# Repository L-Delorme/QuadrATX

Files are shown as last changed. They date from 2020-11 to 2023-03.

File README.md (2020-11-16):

# QuadrATX
ATX mod for the Macintosh Quadra 900/950

This is a work in progress mod. The AC Board has not been fully tested. Use at your own risk.
The BOM has not been finalized. 
Instructions on how to build a QuadrATX kit will follow. 

Hardware protected by CC-BY-NC-SA-4.0 (Attribution-NonCommercial-ShareAlike)
https://creativecommons.org/licenses/by-nc-sa/4.0/

If you wish to sell this product, please contact me beforehand. 
theapplechronicles AT gmail DOT com

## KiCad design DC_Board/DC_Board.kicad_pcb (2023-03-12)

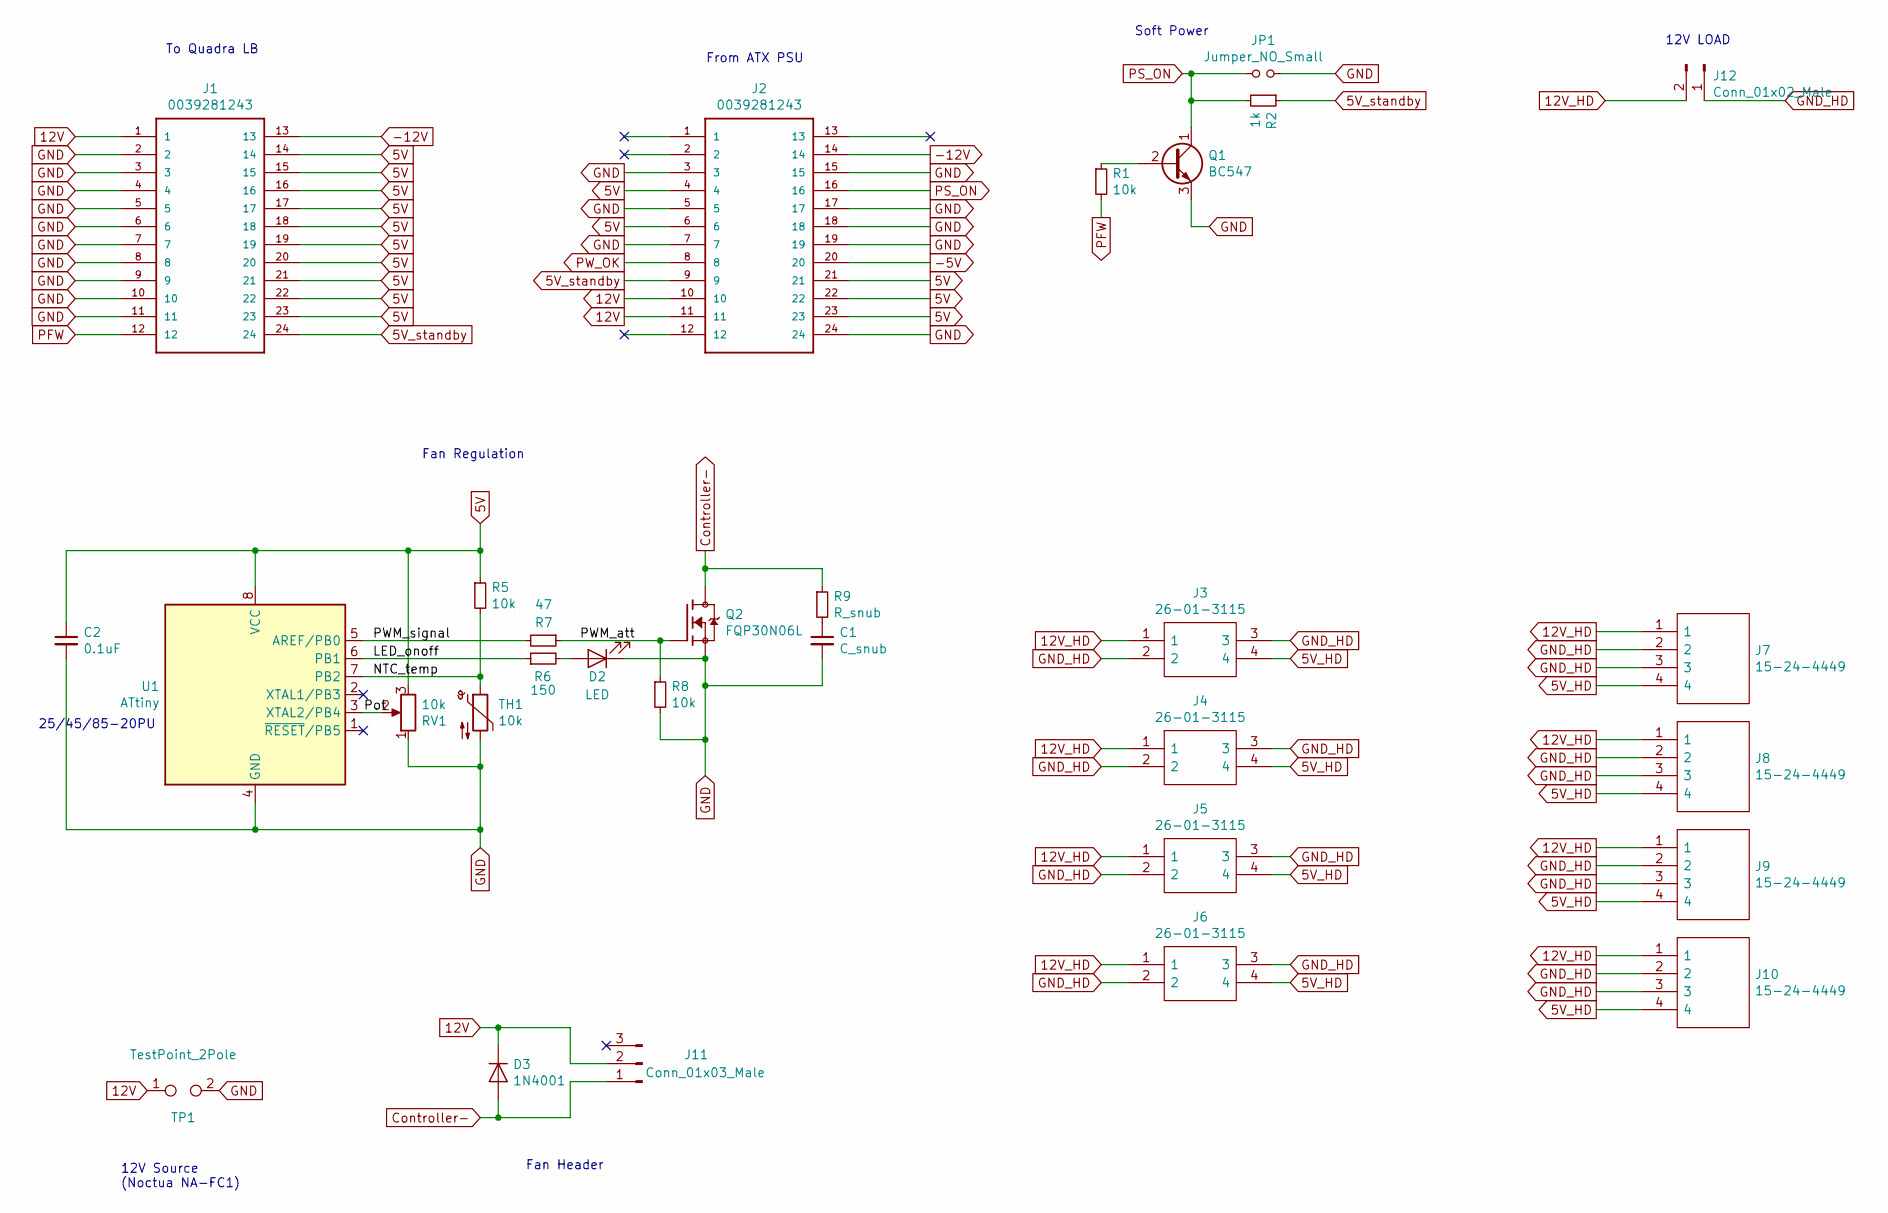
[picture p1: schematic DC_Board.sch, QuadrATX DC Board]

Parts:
C1: C_snub; C_Rect_L9.0mm_W2.5mm_P7.50mm_MKT
C2: 0.1uF; C_Disc_D4.7mm_W2.5mm_P5.00mm
D2: LED; LED_D5.0mm
D3: 1N4001; D_DO-41_SOD81_P10.16mm_Horizontal
J1: 0039281243; Molex_Mini-Fit_Jr_5566-24A2_2x12_P4.20mm_Vertical
J2: 0039281243; Molex_Mini-Fit_Jr_5566-24A_2x12_P4.20mm_Vertical
J3, J4, J5, J6: 26-01-3115; 39-30-1040; Manufacturer_Part_Number 26-01-3115; Mouser Part Number 538-26-01-3115
J7, J8, J9, J10: 15-24-4449; 641737-1; Manufacturer_Part_Number 15-24-4449; Mouser Part Number 538-15-24-4449
J11: Conn_01x03_Male; Molex_KK-254_AE-6410-03A_1x03_P2.54mm_Vertical
J12: Conn_01x02_Male; Molex_KK-396_A-41791-0002_1x02_P3.96mm_Vertical
JP1: Jumper_NO_Small; PinSocket_1x02_P2.54mm_Vertical
Q1: BC547; TO-92L_Wide
Q2: FQP30N06L; TO-220F-3_Horizontal_TabDown
R1, R5, R8: 10k; R_Axial_DIN0309_L9.0mm_D3.2mm_P15.24mm_Horizontal
R2: 1k; R_Axial_DIN0309_L9.0mm_D3.2mm_P15.24mm_Horizontal
R6: 150; R_Axial_DIN0309_L9.0mm_D3.2mm_P15.24mm_Horizontal
R7: 47; R_Axial_DIN0309_L9.0mm_D3.2mm_P15.24mm_Horizontal
R9: R_snub; R_Axial_DIN0309_L9.0mm_D3.2mm_P15.24mm_Horizontal
RV1: 10k; 3386P-1-103LF
TH1: 10k; R_Axial_DIN0309_L9.0mm_D3.2mm_P15.24mm_Horizontal
TP1: TestPoint_2Pole; PinHeader_2x01_P2.54mm_Vertical
U1: ATtiny; DIP-8_W7.62mm

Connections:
5V: C2.1, J1.14, J1.15, J1.16, J1.17, J1.18, J1.19, J1.20, J1.21, J1.22, J1.23, J2.4, J2.6, J2.21, J2.22, J2.23, R5.1, RV1.3, U1.8 (VCC)
5V_HD: J3.4, J4.4, J5.4, J6.4, J7.4, J8.4, J9.4, J10.4
5V_standby: J1.24, J2.9, R2.1
12V: D3.1 (K), J1.1, J2.10, J2.11, J11.2, TP1.1
12V_HD: J3.1, J4.1, J5.1, J6.1, J7.1, J8.1, J9.1, J10.1, J12.2
-5V: J2.20
-12V: J1.13, J2.14
/LED_onoff: R6.1, U1.6 (PB1)
/NTC_temp: R5.2, TH1.1, U1.7 (PB2)
/PWM_att: Q2.1, R7.1, R8.1
/PWM_signal: R7.2, U1.5 (AREF/PB0)
/Pot: RV1.2, U1.3 (XTAL2/PB4)
Controller-: D3.2 (A), J11.1, Q2.2, R9.1
GND: C1.2, C2.2, D2.1 (K), J1.2, J1.3, J1.4, J1.5, J1.6, J1.7, J1.8, J1.9, J1.10, J1.11, J2.3, J2.5, J2.7, J2.15, J2.17, J2.18, J2.19, J2.24, JP1.2, Q1.3 (E), Q2.3, R8.2, RV1.1, TH1.2, TP1.2, U1.4 (GND)
GND_HD: J3.2, J3.3, J4.2, J4.3, J5.2, J5.3, J6.2, J6.3, J7.2, J7.3, J8.2, J8.3, J9.2, J9.3, J10.2, J10.3, J12.1
unnamed: C1.1, R9.2
unnamed: D2.2 (A), R6.2
unnamed: Q1.2 (B), R1.1
PFW: J1.12, R1.2
PS_ON: J2.16, JP1.1, Q1.1 (C), R2.2
PW_OK: J2.8

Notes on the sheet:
From ATX PSU
Soft Power
12V LOAD
To Quadra LB
Fan Regulation
25/45/85-20PU
12V Source (Noctua NA-FC1)
Fan Header

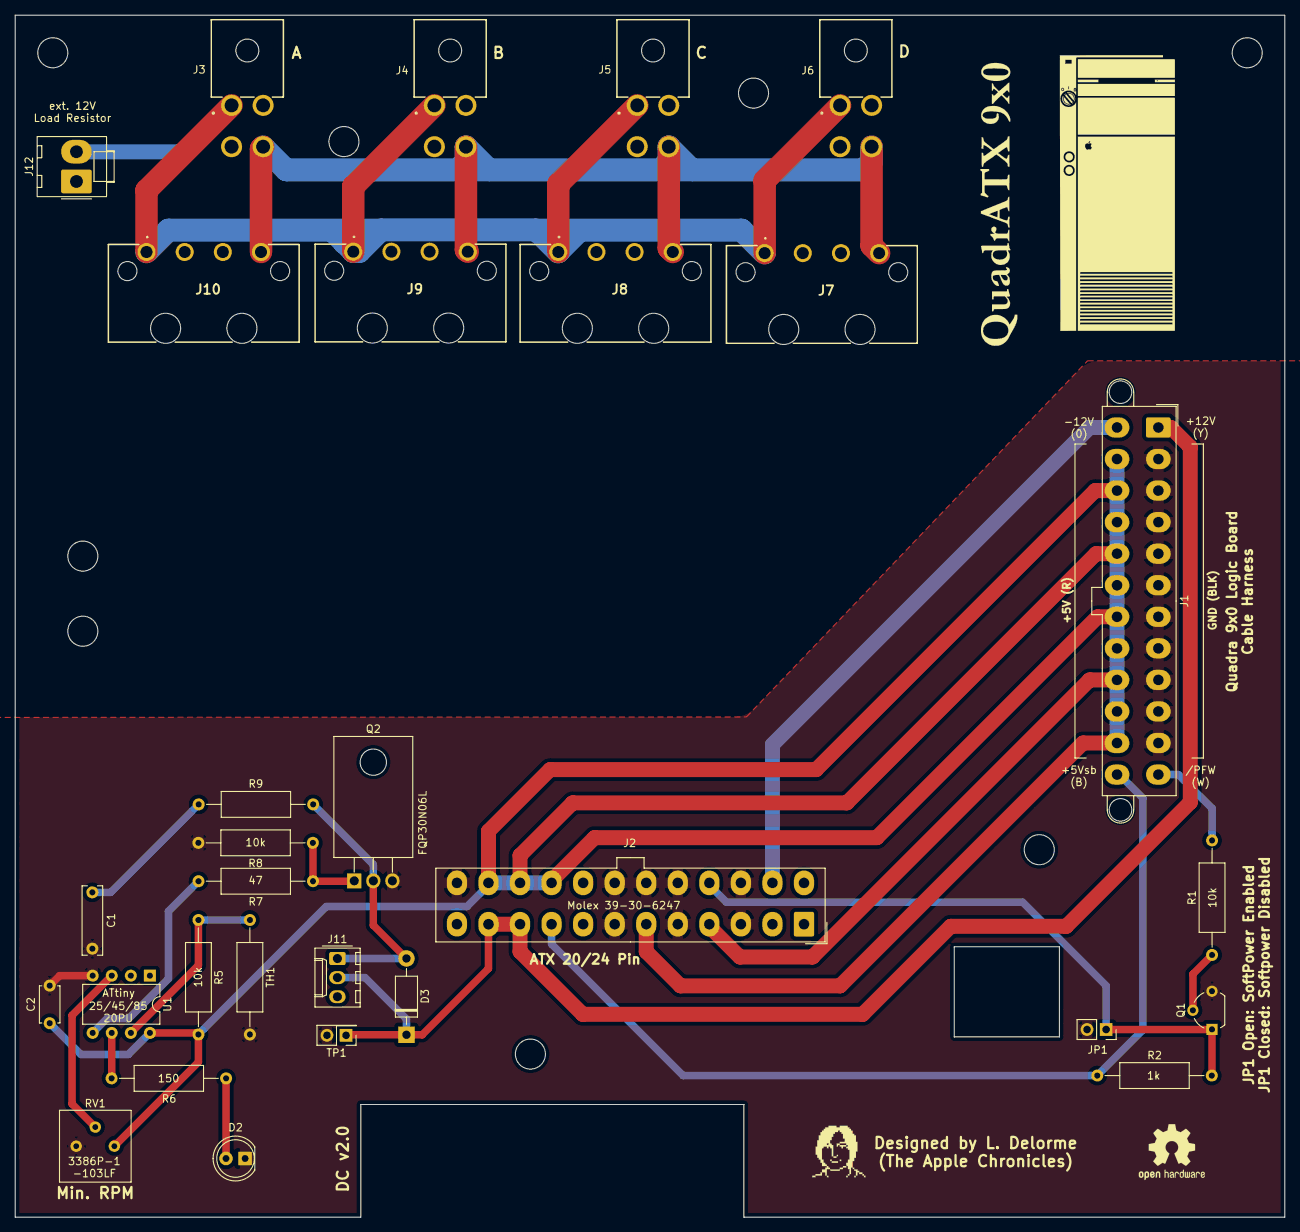
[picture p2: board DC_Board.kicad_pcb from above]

Board: 2 copper layers, 169.0 x 160.0 mm, 30 parts (0 on the bottom side), 19 nets.

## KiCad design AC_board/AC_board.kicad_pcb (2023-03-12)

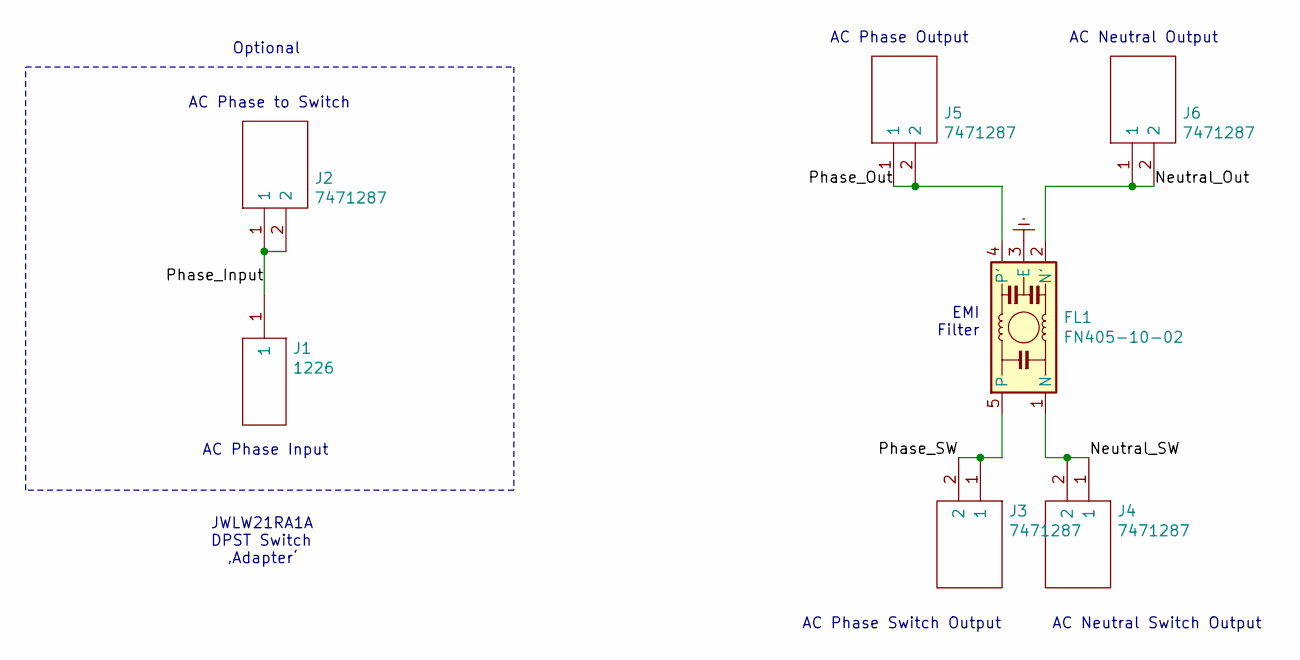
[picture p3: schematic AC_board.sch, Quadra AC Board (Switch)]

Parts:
FL1: FN405-10-02; Filter_Schaffner_FN405
J1: 1226; JST_LV; Manufacturer_Part_Number 1226; Mouser Part Number 534-1226
J2, J3, J4, J5, J6: 7471287; 7471287_large; Manufacturer_Part_Number 7471287; Mouser Part Number 710-7471287

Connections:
/Neutral_Out: FL1.2 (N'), J6.1, J6.2
/Neutral_SW: FL1.1 (N), J4.1, J4.2
/Phase_Input: J1.1, J2.1, J2.2
/Phase_Out: FL1.4 (P'), J5.1, J5.2
/Phase_SW: FL1.5, J3.1, J3.2
Earth: FL1.3 (E)

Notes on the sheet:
EMI Filter
AC Neutral Output
AC Phase Output
AC Phase Input
AC Neutral Switch Output
JWLW21RA1A DPST Switch ‚Adapter‘
AC Phase Switch Output
AC Phase to Switch
Optional

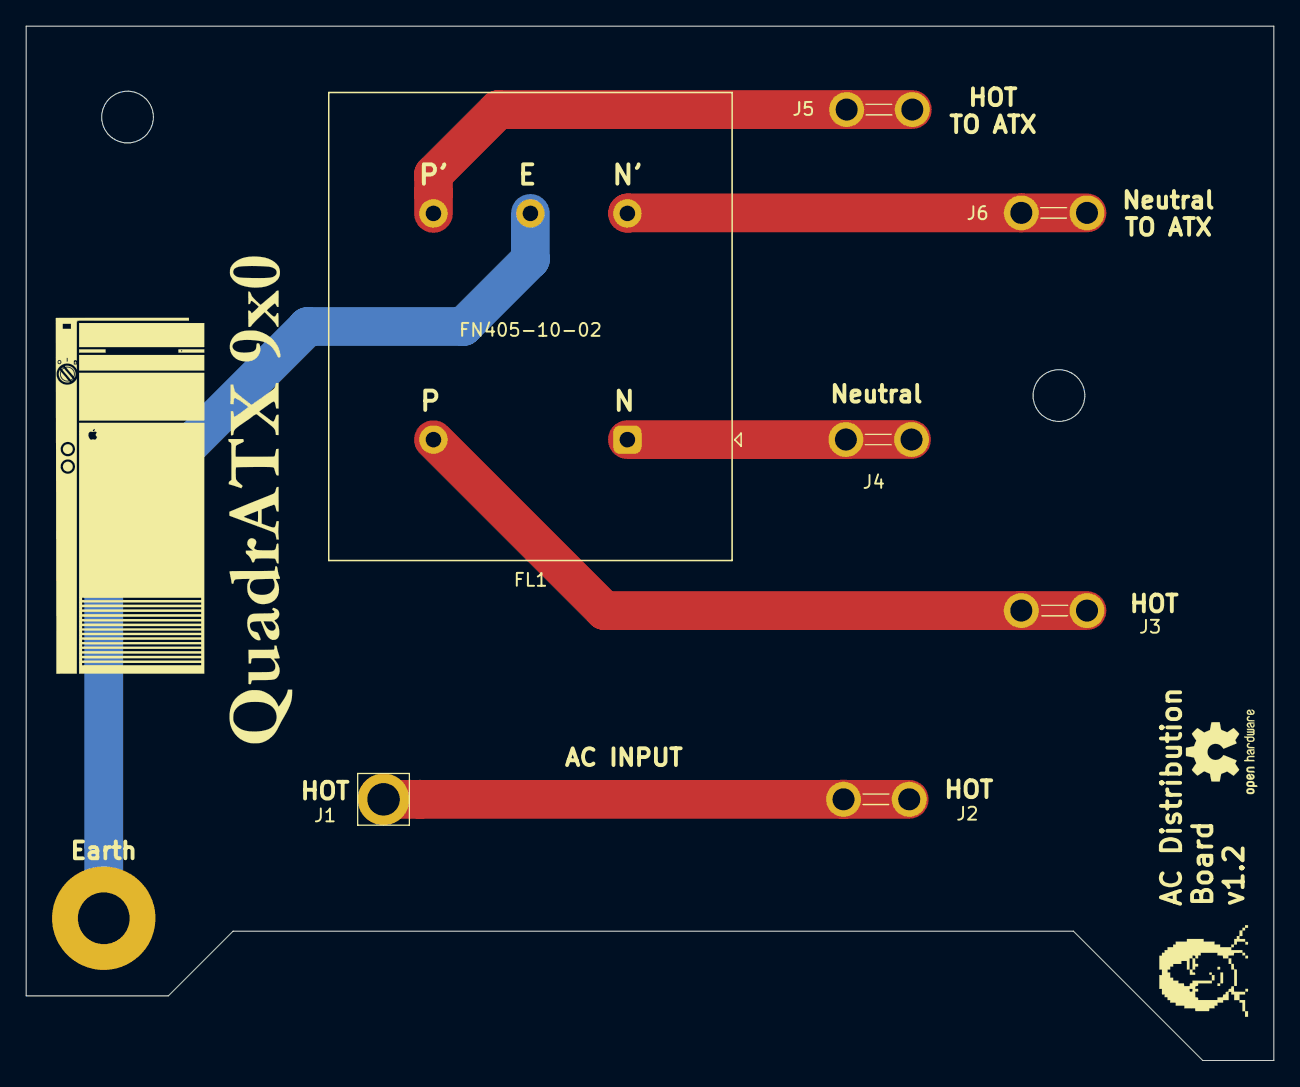
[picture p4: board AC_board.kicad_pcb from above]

Board: 2 copper layers, 96.5 x 80.0 mm, 7 parts (0 on the bottom side), 5 nets.

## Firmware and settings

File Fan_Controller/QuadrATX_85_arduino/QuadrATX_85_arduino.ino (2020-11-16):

// QuadrATX fan speed controller //
//     The Apple Chronicles     //
//           v0.30A            //


// NOTES:
// arduino version


// variables declaration
int SensorPin = A0;  // pin 7
int PWMPin = 3;   // pin 5
int PotPin = A1; // pin 3
int LEDPin = 8; // pin 6
//int SpeedPin = PB3; // pin 2
int SensorVal; // "temperature" from NTC
int PWMVal;   // fan PWM output "speed"
int PotVal;   // real potentiometer value, to define the cold/normal operation fan speed.
int PotValmapped;  // lowest position shall correspond to the absolute minimum speed (see below) and not OFF, new potentiometer value
int MinSpeed=64; // absolute minimum speed, 0=0% and 255=100%, currently set to 25%, corresponds to lowest pot value

// Calibration variables
int NTCcold=512; // corresponds to ambient temperature, 10K for a 10k NTC @25°C
int NTChot=110; // corresponds to highest temperature before LED lights up, about 1.3K for a 10k NTC @80°C
int PotMin=0; // corresponds to lowest position on potentiometer
int PotMax=1023; // corresponds to highest position on potentiometer


// setup code, to run once
void setup() {
  // set PWM frequency of PB0 (Pin 5, ATTiny85, fan output) to 31,250 Hz.
  //TCCR0B = TCCR0B & 0b11111000 | 0b001;

  // define pin modes ATTiny85
  pinMode(SensorPin, INPUT);
  pinMode(PotPin, INPUT);
  pinMode(PWMPin, OUTPUT);
  pinMode(LEDPin, OUTPUT);
  //pinMode(SpeedPin, OUTPUT);

  Serial.begin(9600);

  // Set fan to full speed for one second at startup (prevents stall)
  analogWrite(PWMPin, 255);
  
  delay(1000);
}


// main code, to run repeatedly
void loop() {

  //read NTC sensor value
  SensorVal = analogRead(SensorPin);
   if( (SensorVal > NTCcold) && (SensorVal < 1000) ){ // in case ambient temperature is lower than 25°C
    SensorVal = NTCcold;} 
   if( (SensorVal > NTCcold) && (SensorVal > 1000) ){ // NTC failure (open circuit)
    SensorVal = NTChot-1;} 
  
  //read pot value
  PotVal = analogRead(PotPin);

  // map and assign pot/pwm values. 0 to 255 corresponds to 0 to 100%
  PotValmapped = map(PotVal, PotMin, PotMax, MinSpeed, 254); // change potentiometer characteristic, lowest position corresponds to absolute minimum speed
  PWMVal = map(SensorVal, NTCcold, NTChot, PotValmapped, 255); // linear fan curve from ambient to LED lighting up. PotValmapped is the minimum fan speed set by the potentiometer

  // Overheating indicator
  if (SensorVal<NTChot){ ///////////////////////// ATTENTION
    PWMVal=255; // full speed
    digitalWrite(LEDPin, HIGH); // LED ON
  }
  else {
    digitalWrite(LEDPin, LOW); // LED OFF
  }

  //write the PWM value to the pwm output pin
  analogWrite(PWMPin, PWMVal);

  //basic RPM indicator
  //analogWrite(SpeedPin, PWMVal);

    // CONSOLE
  Serial.println("NTC Value");
  Serial.println(SensorVal);
  Serial.println(" "); // carriage return
  Serial.println("Pot Value");
  Serial.println(PotVal);
  Serial.println(" "); // carriage return
  Serial.println("Pot mapped");
  Serial.println(PotValmapped);
  Serial.println(" "); // carriage return
  Serial.println("PWMVAL");
  Serial.println(PWMVal);
  Serial.println(" "); // carriage return
  delay(1000); // console and serial will be removed for final release.

}

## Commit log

2020-11-16 Updated AC Gerbers
    [AC_board-B_Cu.gbl, AC_board-B_Mask.gbs, AC_board-B_SilkS.gbo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]
2020-11-16 Fan controller files
2023-03-12 Brand new AC and DC boards
    [AC_board-B_Cu.gbl, AC_board-B_Mask.gbs, AC_board-B_SilkS.gbo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]

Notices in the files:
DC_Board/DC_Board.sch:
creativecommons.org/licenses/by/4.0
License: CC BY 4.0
